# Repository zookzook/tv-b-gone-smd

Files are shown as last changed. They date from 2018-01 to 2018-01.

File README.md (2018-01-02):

# tv-b-gone-smd
The TV B Gone circuit as smd version and using the Arduino IDE for compiling

Ken Shirriff ported the original code of the tv-b-gone for using the Ardunio and the Ardunio IDE.

https://github.com/shirriff/Arduino-TV-B-Gone

I ported this version back for using an Attiny85 and the Arduino IDE for my TV-B-Gone-Clone. 

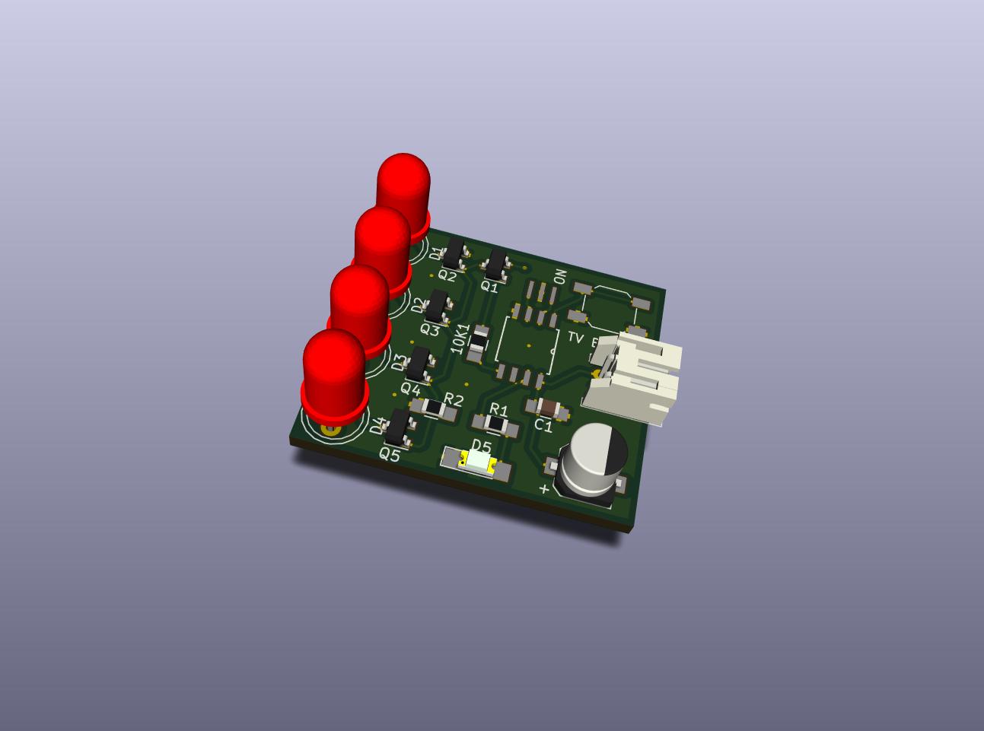
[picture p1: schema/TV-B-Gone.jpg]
The Schema


This is an SMD version of the well known TV-B-Gone circuit. I have modified the software 
for the Attiny85, so that these are compiled with the Arduino IDE. A macro defines whether US or EU 
codes are used. This releases a PIN for other things.

First you have to set the FUSE-Bits for the Attiny85 with a programmer (for example, with an Ardunio itself).
This requires a ceramic resonator with 8Mhz. In the Ardunio IDE you call
"burn bootloader", but only FUSE bits are set in case of an Attiny85. Then the program can be 
transmitted to the chip as usual. If you don't attach the ceramic resonator it is not possible 
to program the Attiny85 any more.

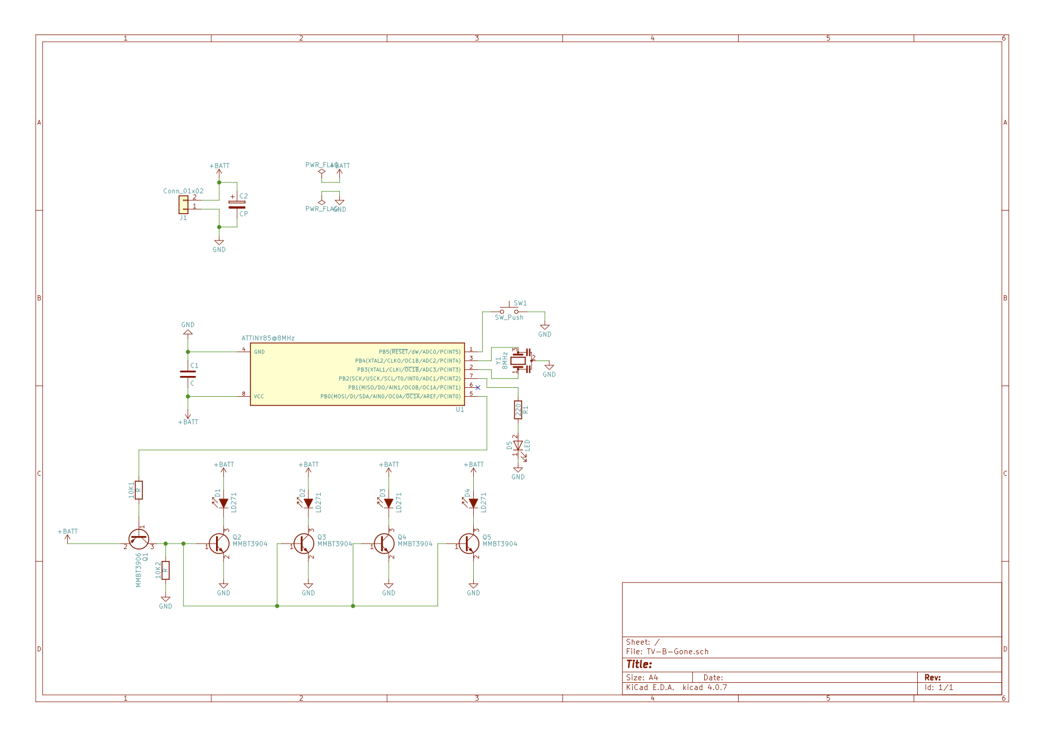
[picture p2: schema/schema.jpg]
The Schema


The result looks like this. It is very small! Now I looking for a nice housing.

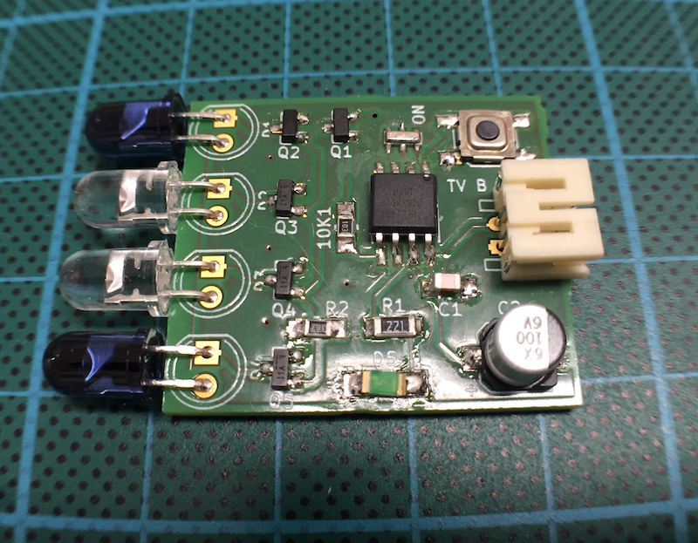
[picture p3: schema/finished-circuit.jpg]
The Schema


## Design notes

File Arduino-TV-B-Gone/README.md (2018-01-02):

# Description:  
This code is the TV-B-Gone library ported to run on the Attiny85 back but using the Arduino IDE.  

# README.md update history:  
Readme Last Updated: 22 Oct. 2016  
By Gabriel Staples, http://www.ElectricRCAircraftGuy.com  
-My contact info is available by clicking the "Contact Me" tab at the top of my website.  

# Current Code Version & History:  
-see Arduino_TV_B_Gone.ino for full version history 

Semver (http://semver.org/) VERSION HISTORY (newest on top):  
(date format: yyyymmdd; ex: 20161022 is 22 Oct. 2016)  
 - 20161022 - v1.3 - Semver versioning implemented; various code updates, clarifications, & comment additions, and changes to fix PROGMEM incompatibilities so it will now compile with latest versions of gcc compiler; also improved blink indicator routines & added the ability to stop the code-sending sequence once it has begun; by Gabriel Staples (http://www.ElectricRCAircraftGuy.com)  
 - 20101023 - v1.2 - Latest version posted by Ken Shirriff on his website here (http://www.righto.com/2010/11/improved-arduino-tv-b-gone.html) (direct download link here: http://arcfn.com/files/arduino-tv-b-gone-1.2.zip)  
 - 20101018 - v1.2 - Universality for EU (European Union) & NA (North America) added by Mitch Altman; sleep mode added by ka1kjz  
 - 2010____ - v1.2 - code ported to Arduino; by Ken Shirriff  
 - 20090816 - v1.2 - for ATtiny85v, by Mitch Altman & Limor Fried (https://www.adafruit.com/), w/some code by Kevin Timmerman & Damien Good  

# Description:  
This code is the TV-B-Gone library ported to run on the Arduino.  

# Background:
-see Arduino_TV_B_Gone.ino for latest version history & more details. 

Updated code to fix PROGMEM incompatiblities--now works with latest versions of gcc compiler & Arduino IDE
-with other improvements also
By Gabriel Staples (http://www.ElectricRCAircraftGuy.com)

This port to Arduino is by Ken Shirriff.  
For background details on the Arduino port, how to build it, and how to use it, see:  
 * http://www.arcfn.com/2009/12/tv-b-gone-for-arduino.html and here:
 * http://www.righto.com/2010/11/improved-arduino-tv-b-gone.html (newer)

For information on the original TV-B-Gone see:  
http://www.tvbgone.com/. Mitch Altman is the inventor of the original TV-B-Gone.    

The original code is:  
TV-B-Gone Firmware version 1.2  
 for use with ATtiny85v and v1.2 hardware  
 (c) Mitch Altman + Limor Fried 2009  
 Last edits, August 16 2009  

Added universality for EU or NA, and Sleep mode to Ken's Arduino port.  
 -- Mitch Altman  18-Oct-2010  
Thanks to ka1kjz for the code for adding Sleep  
    <http://www.ka1kjz.com/561/adding-sleep-to-tv-b-gone-code/>  

With some code from:  
Kevin Timmerman & Damien Good 7-Dec-07  

# License:  
Distributed under Creative Commons 2.5 -- Attribution & Share Alike  

# CIRCUIT:  
-NB: SEE "main.h" TO VERIFY DEFINED PINS TO USE  
The hardware for this project uses an Arduino:  
 * Connect an IR LED to pin 3 (IRLED).  
 * Connect a visible LED to the pin 13 (or use the built-in LED in many Arduinos).  
 * Connect a push-button between pin 2 (TRIGGER) and ground.  
 * Pin 5 (REGIONSWITCH) must be left floating for North America, or wire it to ground to have it output European codes.  

# User Manual:  
## Background Settings:  
 * The TV-B-Gone for Arduino can use either the EU (European Union) or the NA (North America) database of POWER CODES  
 * EU is for Europe, Middle East, Australia, New Zealand, and some countries in Africa and South America  
 * NA is for North America, Asia, and the rest of the world not covered by EU  
 * Let pin 5 float for NA codes, or wire it to ground to have it send EU codes  
 * Serial debugging output can be activated by setting "DEBUG 0" to "DEBUG 1" in "main.h"  
 * For 8 MHz Arduinos, define DELAY_CNT as 11 in "main.h," or use 25 for 16 MHz Arduinos.
  * Fine-tune if necessary  
 * All IR codes are defined in "WORLD_IR_CODES.h"  
  * We'd love to have you add more! Just be careful NOT to duplicate codes please!  
  
## Use:  
 * When the device is first powered on, it will quick-flash (30ms on-time followed by 250ms off-time) 3 times if set to output NA (North America) codes, or 6 times for EU (European Union) codes. See the end of the "setup()" function.  
 * Once on, the device will enter sleep mode, where it will remain until a button press occurs on the TRIGGER pin, at which point it will wake up and send all of its power codes for the region set according to the state of the REGIONSWITCH pin.  
 * Once you press the TRIGGER button (on pin 2), all power codes will be sent sequentially, one after the other. Note that the trigger button debouncing is done in a very primitive fashion, so quick button presses and releases (<500ms) may work best. If you just hold down the button, the code sending sequence will be continually started, stopped, and started again, since a button press during code sending is used to stop the sending sequence.  
 * After each individual IR power code is sent, a quick flash will occur on the visible LED (30ms on-time) to indicate a code was just sent. Therefore, as the codes are sent, you will see the visible LED flash repeatedly.  
 * Once all codes have been sent (which takes around 60 sec or so), a ~1.3 sec pause followed by 8 quick flashes will occur to indicate that all power codes have been sent. Then, the device will go back into sleep mode until another TRIGGER button press occurs.  
 * Between individual power codes, the TRIGGER button is read one time. If it is read as pressed (LOW), the code sending sequence will be stopped early. This will be indicated by a ~705ms delay followed by 4 quick-flashes, followed by another ~1.3 sec delay to give you time to release the button.  
  * NB: since the TRIGGER button is only read between individual codes, rather than continuously, you may need to hold down the button for a half-second to second or so for it to be read properly as pressed. Once the delay and 4 quick-flashes begin, you can release the button, and the power codes will be stopped. The device will enter back into sleep mode. Press the button again to begin the code sequence again from the beginning.  
  * NB: If you keep holding the button, however, this will be read as a new button-press in the main loop and the sequence will be restarted. Therefore, continually holding the button will just keep starting and stopping and starting again the sending sequence, repeatedly.

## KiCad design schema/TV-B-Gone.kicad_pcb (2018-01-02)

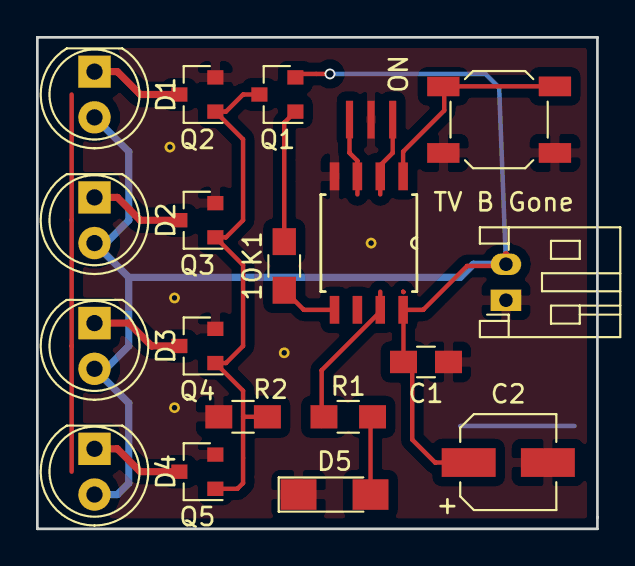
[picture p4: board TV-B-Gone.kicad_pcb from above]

Board: 2 copper layers, 31.1 x 27.3 mm, 19 parts (0 on the bottom side), 14 nets.

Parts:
10K1: R; R_0805_HandSoldering
C1: C; C_0805_HandSoldering
C2: CP; CP_Elec_5x5.3
D1, D2, D3, D4: LD271; LED_D5.0mm
D5: LED; LED_1206_HandSoldering
J1: Conn_01x02; JST_PH_S2B-PH-K_02x2.00mm_Angled
ON: SW_Push; SW_SPST_SKQG
Q1: MMBT3906; SOT-23
Q2, Q3, Q4, Q5: MMBT3904; SOT-23
R1: 220; R_0805_HandSoldering
R2: R; R_0805_HandSoldering
U1: ATTINY85@8MHz; SOIC127P798X216-8N
Y1: 8MHz; CSTCE8M00G55-R0

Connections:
+BATT: C1.2, C2.1, D1.2, D2.2, D3.2, D4.2, J1.2, Q1.2, U1.8
GND: C1.1, C2.2, D5.1, J1.1, ON.2, Q2.2, Q3.2, Q4.2, Q5.2, R2.1, U1.4, Y1.2
unnamed: 10K1.1, Q1.1
unnamed: 10K1.2, U1.5
unnamed: Q1.3, Q2.1, Q3.1, Q4.1, Q5.1, R2.2
unnamed: D1.1, Q2.3
unnamed: D2.1, Q3.3
unnamed: D3.1, Q4.3
unnamed: D4.1, Q5.3
unnamed: D5.2, R1.2
unnamed: R1.1, U1.7
unnamed: ON.1, U1.1
unnamed: U1.2, Y1.1
unnamed: U1.3, Y1.3

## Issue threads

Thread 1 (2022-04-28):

Porting to ESP32-S2?

glowingkitty, 2022-04-28:
Hey there. Thanks for the work with this SMD version of TV-B gone ^.^ Since I find the ESP32-S2 easier to buy then the Attiny85, I was thinking about building an SMD version of TV-B gone with the ESP32-S2. Are you aware of any possible reasons why this shouldn't work or should be tricky? Anything I should consider changing in the code?

zookzook, 2022-05-03:
Hey,

mmmm....good question. The only thing (that I can remember) is about the signal timing of the LEDs. The ESP32-S2 has more timers so you need to find and configure the right time for sending the signal.

glowingkitty, 2022-05-03:
so you defined the correct timing for the Attiny85 in the code? In what part of the code would I need to look for that? Also, since I don't have a TV at home or at the local Hackspace where I mostly work on electronics - any recommendations how else one can test the tv b gone?:D With an oscilloscope?

glowingkitty, 2022-05-03:
oh and what about porting to an rp2040 instead? Same story?

zookzook, 2022-05-03:
Check this function: https://github.com/zookzook/tv-b-gone-smd/blob/e84a07bffbf0dc2af1246818fa87e6c1f06e40c9/Arduino-TV-B-Gone/Arduino-TV-B-Gone.ino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

zookzook, 2022-05-03:
Maybe you just buy an Attiny85 :-)

glowingkitty, 2022-05-04:
> Maybe you just buy an Attiny85 :-)

If I would find a place where they are in stock… sure ;)

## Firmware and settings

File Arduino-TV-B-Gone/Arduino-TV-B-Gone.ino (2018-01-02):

/*
TV-B-Gone Firmware version 1.2
for use with ATtiny85v and v1.2 hardware
(c) Mitch Altman + Limor Fried 2009
Last edits, August 16 2009

With some code from:
Kevin Timmerman & Damien Good 7-Dec-07

Modified for Attiny85 01/02/2018

Distributed under Creative Commons 2.5 -- Attib & Share Alike

*/

#include <avr/io.h>             // this contains all the IO port definitions
#include <avr/eeprom.h>
#include <avr/sleep.h>          // definitions for power-down modes
#include <avr/pgmspace.h>       // definitions or keeping constants in program memory
#include <avr/wdt.h>

#include "WORLD_IR_CODES.h"


/*
This project transmits a bunch of TV POWER codes, one right after the other, 
with a pause in between each.  (To have a visible indication that it is 
transmitting, it also pulses a visible LED once each time a POWER code is 
transmitted.)  That is all TV-B-Gone does.  The tricky part of TV-B-Gone 
was collecting all of the POWER codes, and getting rid of the duplicates and 
near-duplicates (because if there is a duplicate, then one POWER code will 
turn a TV off, and the duplicate will turn it on again (which we certainly 
do not want).  I have compiled the most popular codes with the 
duplicates eliminated, both for North America (which is the same as Asia, as 
far as POWER codes are concerned -- even though much of Asia USES PAL video) 
and for Europe (which works for Australia, New Zealand, the Middle East, and 
other parts of the world that use PAL video).

Before creating a TV-B-Gone Kit, I originally started this project by hacking 
the MiniPOV kit.  This presents a limitation, based on the size of
the Atmel ATtiny2313 internal flash memory, which is 2KB.  With 2KB we can only 
fit about 7 POWER codes into the firmware's database of POWER codes.  However,
the more codes the better! Which is why we chose the ATtiny85 for the 
TV-B-Gone Kit.

This version of the firmware has the most popular 100+ POWER codes for 
North America and 100+ POWER codes for Europe. 

In this version the POWER codes are selected by a macro:

#define US_CODES 1

to use the US codes or

#define EU_CODES 1

to use the EU codes. This means the a pin is left!

*/


/*
This project is a good example of how to use the AVR chip timers.
*/


/*
The hardware for this project is very simple:
     ATtiny85 has 8 pins:
       pin 1   RST + Button
       pin 2   one pin of ceramic resonator MUST be 8.0 mhz
       pin 3   other pin of ceramic resonator
       pin 4   ground
       pin 5   OC1A - IR emitters, through a '2907 PNP driver that connects 
               to 4 (or more!) PN2222A drivers, with 1000 ohm base resistor 
               and also connects to programming circuitry
       pin 7   PB0 - visible LED, and also connects to programming circuitry
       pin 8   +3-5v DC (such as 2-4 AA batteries!)
    See the schematic for more details.

    This firmware requires using an 8.0MHz ceramic resonator 
       (since the internal oscillator may not be accurate enough).

    IMPORTANT:  to use the ceramic resonator, you must perform the following:
                    make burn-fuse_cr
*/

extern const IrCode* const PowerCodes[] PROGMEM;
extern uint8_t num_codes;

/* This function is the 'workhorse' of transmitting IR codes.
   Given the on and off times, it turns on the PWM output on and off
   to generate one 'pair' from a long code. Each code has ~50 pairs! */
void xmitCodeElement(uint16_t ontime, uint16_t offtime, uint8_t PWM_code )
{
  // start Timer0 outputting the carrier frequency to IR emitters on and OC0A 
  // (PB0, pin 5)
  TCNT0 = 0; // reset the timers so they are aligned
  TIFR = 0;  // clean out the timer flags

  if(PWM_code) {
    // 99% of codes are PWM codes, they are pulses of a carrier frequecy
    // Usually the carrier is around 38KHz, and we generate that with PWM
    // timer 0
    TCCR0A =_BV(COM0A0) | _BV(WGM01);          // set up timer 0
    TCCR0B = _BV(CS00);
  } else {
    // However some codes dont use PWM in which case we just turn the IR
    // LED on for the period of time.
    PORTB &= ~_BV(IRLED);
  }

  // Now we wait, allowing the PWM hardware to pulse out the carrier 
  // frequency for the specified 'on' time
  delay_ten_us(ontime);
  
  // Now we have to turn it off so disable the PWM output
  TCCR0A = 0;
  TCCR0B = 0;
  // And make sure that the IR LED is off too (since the PWM may have 
  // been stopped while the LED is on!)
  PORTB |= _BV(IRLED);           // turn off IR LED

  // Now we wait for the specified 'off' time
  delay_ten_us(offtime);
}

/* This is kind of a strange but very useful helper function
   Because we are using compression, we index to the timer table
   not with a full 8-bit byte (which is wasteful) but 2 or 3 bits.
   Once code_ptr is set up to point to the right part of memory,
   this function will let us read 'count' bits at a time which
   it does by reading a byte into 'bits_r' and then buffering it. */

uint8_t bitsleft_r = 0;
uint8_t bits_r=0;
PGM_P code_ptr;

// we cant read more than 8 bits at a time so dont try!
uint8_t read_bits(uint8_t count)
{
  uint8_t i;
  uint8_t tmp=0;
  
  // we need to read back count bytes
  for (i=0; i<count; i++) {
    // check if the 8-bit buffer we have has run out
    if (bitsleft_r == 0) {
      // in which case we read a new byte in
      bits_r = pgm_read_byte(code_ptr++);
      // and reset the buffer size (8 bites in a byte)
      bitsleft_r = 8;
    }
    // remove one bit
    bitsleft_r--;
    // and shift it off of the end of 'bits_r'
    tmp |= (((bits_r >> (bitsleft_r)) & 1) << (count-1-i));
  }
  // return the selected bits in the LSB part of tmp
  return tmp; 
}


/*
The C compiler creates code that will transfer all constants into RAM when 
the microcontroller resets.  Since this firmware has a table (powerCodes) 
that is too large to transfer into RAM, the C compiler needs to be told to 
keep it in program memory space.  This is accomplished by the macro PROGMEM 
(this is used in the definition for powerCodes).  Since the C compiler assumes 
that constants are in RAM, rather than in program memory, when accessing
powerCodes, we need to use the pgm_read_word() and pgm_read_byte macros, and 
we need to use powerCodes as an address.  This is done with PGM_P, defined 
below.  
For example, when we start a new powerCode, we first point to it with the 
following statement:
    PGM_P thecode_p = pgm_read_word(powerCodes+i);
The next read from the powerCode is a byte that indicates the carrier 
frequency, read as follows:
      const uint8_t freq = pgm_read_byte(code_ptr++);
After that is a byte that tells us how many 'onTime/offTime' pairs we have:
      const uint8_t numpairs = pgm_read_byte(code_ptr++);
The next byte tells us the compression method. Since we are going to use a
timing table to keep track of how to pulse the LED, and the tables are 
pretty short (usually only 4-8 entries), we can index into the table with only
2 to 4 bits. Once we know the bit-packing-size we can decode the pairs
      const uint8_t bitcompression = pgm_read_byte(code_ptr++);
Subsequent reads from the powerCode are n bits (same as the packing size) 
that index into another table in ROM that actually stores the on/off times
      const PGM_P time_ptr = (PGM_P)pgm_read_word(code_ptr);
*/


int main(void) {
  uint16_t ontime, offtime;
  uint8_t i,j;
  
  TCCR1 = 0;                      // Turn off PWM/freq gen, should be off already
  TCCR0A = 0;
  TCCR0B = 0;

  i = MCUSR;                     // Save reset reason
  MCUSR = 0;                     // clear watchdog flag
  WDTCR = _BV(WDCE) | _BV(WDE);  // enable WDT disable

  WDTCR = 0;                     // disable WDT while we setup

  DDRB = _BV(LED) | _BV(IRLED);   // set the visible and IR LED pins to outputs
  PORTB = _BV(IRLED);             // turn off the IR LED

  // check the reset flags
  if (i & _BV(BORF)) {    // Brownout
    // Flash out an error and go to sleep
    flashslowLEDx(2); 
    tvbgone_sleep();  
  }

  delay_ten_us(5000);            // Let everything settle for a bit
  
  // Tell the user what region we're in  - 3 is US 4 is EU
  quickflashLEDx(3);
  
  // Starting execution loop
  delay_ten_us(25000);

  // We are done, no need for a watchdog timer anymore
  wdt_disable();
  
   j = num_codes;

  // for every POWER code in our collection
  for(i=0 ; i < j; i++) {   

    code_ptr = (PGM_P)pgm_read_word( PowerCodes + i );  
    
    // Read the carrier frequency from the first byte of code structure
    const uint8_t freq = pgm_read_byte(code_ptr++);
    // set OCR for Timer1 to output this POWER code's carrier frequency
    OCR0A = freq; 
    
    // Get the number of pairs, the second byte from the code struct
    const uint8_t numpairs = pgm_read_byte(code_ptr++);

    // Get the number of bits we use to index into the timer table
    // This is the third byte of the structure
    const uint8_t bitcompression = pgm_read_byte(code_ptr++);

    // Get pointer (address in memory) to pulse-times table
    // The address is 16-bits (2 byte, 1 word)
    PGM_P time_ptr = (PGM_P)pgm_read_word(code_ptr);
    
    code_ptr+=2;

    code_ptr = (PGM_P)pgm_read_word(code_ptr);

    // Transmit all codeElements for this POWER code 
    // (a codeElement is an onTime and an offTime)
    // transmitting onTime means pulsing the IR emitters at the carrier 
    // frequency for the length of time specified in onTime
    // transmitting offTime means no output from the IR emitters for the 
    // length of time specified in offTime

    // For EACH pair in this code....
    for (uint8_t k=0; k<numpairs; k++) {
        uint8_t ti;
        
        // Read the next 'n' bits as indicated by the compression variable
        // The multiply by 4 because there are 2 timing numbers per pair
        // and each timing number is one word long, so 4 bytes total!
        ti = (read_bits(bitcompression)) * 4;
      
        // read the onTime and offTime from the program memory
        ontime = pgm_read_word(time_ptr+ti);  // read word 1 - ontime
        offtime = pgm_read_word(time_ptr+ti+2);  // read word 2 - offtime
      
        // transmit this codeElement (ontime and offtime)
        xmitCodeElement(ontime, offtime, (freq!=0));  
    } 
    
    //Flush remaining bits, so that next code starts
    //with a fresh set of 8 bits.
    bitsleft_r=0; 

    // delay 250 milliseconds before transmitting next POWER code
    delay_ten_us(25000);
    
    // visible indication that a code has been output.
    quickflashLED(); 
  }
  
  // flash the visible LED on PB0  4 times to indicate that we're done
  delay_ten_us(65500); // wait maxtime 
  delay_ten_us(65500); // wait maxtime 
  quickflashLEDx(4);

  tvbgone_sleep();
}


/****************************** SLEEP FUNCTIONS ********/

void tvbgone_sleep( void )
{
  // Shut down everything and put the CPU to sleep
  TCCR0A = 0;           // turn off frequency generator (should be off already)
  TCCR0B = 0;           // turn off frequency generator (should be off already)
  PORTB |= _BV(IRLED);     // turn off IR LED
  PORTB &= ~_BV(LED);   // turn off visible 

  delay_ten_us(1000);      // wait 10 millisec

  MCUCR = _BV(SM1) |  _BV(SE);    // power down mode,  SE enables Sleep Modes
  sleep_cpu();                    // put CPU into Power Down Sleep Mode
}


/****************************** LED AND DELAY FUNCTIONS ********/


// This function delays the specified number of 10 microseconds
// it is 'hardcoded' and is calibrated by adjusting DELAY_CNT 
// in main.h Unless you are changing the crystal from 8mhz, dont
// mess with this.
void delay_ten_us(uint16_t us) {
  uint8_t timer;
  while (us != 0) {
    // for 8MHz we want to delay 80 cycles per 10 microseconds
    // this code is tweaked to give about that amount.
    for (timer=0; timer <= DELAY_CNT; timer++) {
      NOP;
      NOP;
    }
    NOP;
    us--;
  }
}


// This function quickly pulses the visible LED (connected to PB0, pin 5)
// This will indicate to the user that a code is being transmitted
void quickflashLED( void ) {
  PORTB |= _BV(LED);    // turn off visible LED at PB0 by pulling pin to +3V
  delay_ten_us(3000);   // 30 millisec delay
  PORTB &= ~_BV(LED);   // turn on visible LED at PB0 by pulling pin to ground
}

// This function just flashes the visible LED a couple times, used to
// tell the user what region is selected
void quickflashLEDx( uint8_t x ) {
  while( x > 0 ) {
     PORTB |= _BV(LED);    // turn off visible LED at PB0 by pulling pin to +3V
     delay_ten_us(10000);     // 150 millisec delay between flahes
     PORTB &= ~_BV(LED);   // turn on visible LED at PB0 by pulling pin to ground
     delay_ten_us(10000);     // 150 millisec delay between flahes
     x-= 1;
  }
}

// This is like the above but way slower, used for when the tvbgone
// crashes and wants to warn the user
void flashslowLEDx( uint8_t num_blinks )
{
  uint8_t i;
  for(i=0;i<num_blinks;i++)
    {
      PORTB |= _BV(LED);          
      delay_ten_us(50000);     // 500 millisec delay
      PORTB &= ~_BV(LED);    
      delay_ten_us(50000);     // 500 millisec delay
    }
}

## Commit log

2018-01-02 Initial version
    [TV-B-Gone.kicad_pcb, TV-B-Gone.sch]
2018-01-02 Linked mod-file added, images of circuit and schema added
